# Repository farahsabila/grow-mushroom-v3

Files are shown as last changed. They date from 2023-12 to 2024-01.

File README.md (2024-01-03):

# IoT-based Mushroom Cultivation Device v3
This was my Exhibition Project that I showcased at INAGRITECH 2023 on August 23 - 25, 2023. This prototype was made for growing any mushroom at home. 

Pameran

## How It Works
Air humidity, air temperature, and light intensity are being monitored and controlled using IoT Technology. 

With these parameter specifications:
1. Air humidity: 70 % - 95 %
2. Air temperature: 20 °C - 25 °C
3. Light intensity: 300 lx - 500 lx

This range parameter specification can be adjusted according to the type of mushroom being chosen.

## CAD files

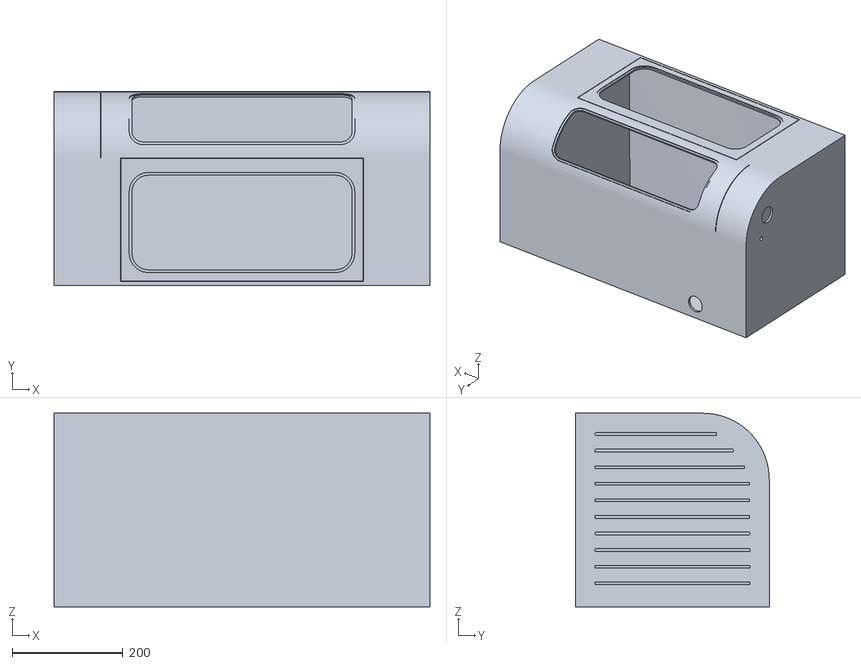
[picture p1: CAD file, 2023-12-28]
Casing/Main Casing.stl
680.0 x 350.0 x 350.0

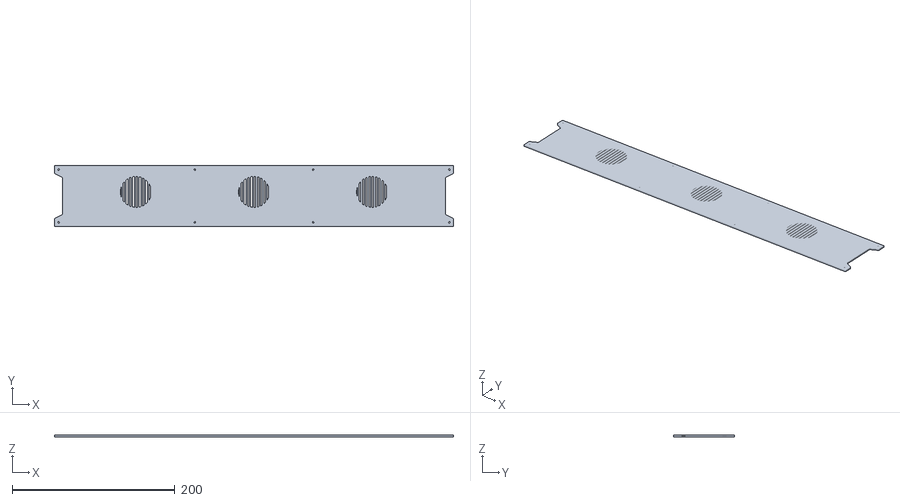
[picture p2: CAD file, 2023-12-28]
Casing/Inside Fan Closure/Lid_Closure.stl
490.0 x 75.0 x 2.00

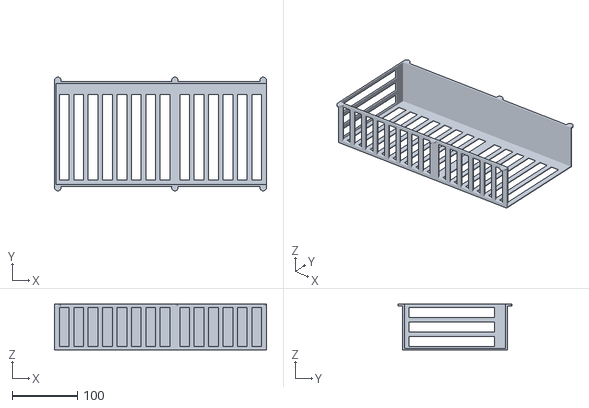
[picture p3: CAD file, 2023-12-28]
Casing/Outside Fan Closure/Right Body.stl
324.0 x 174.0 x 70.0

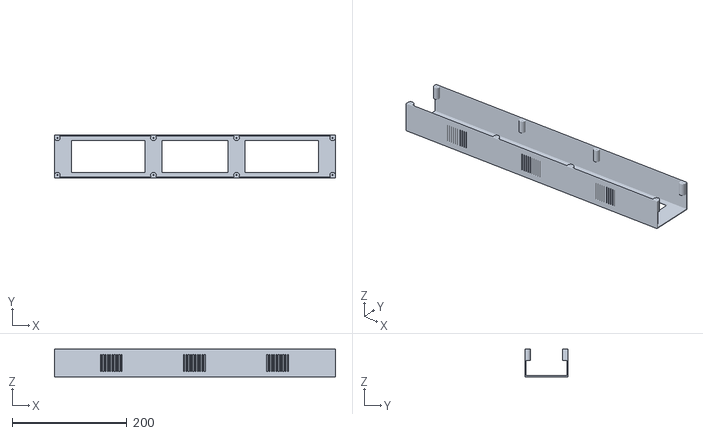
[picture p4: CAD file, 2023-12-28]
Casing/Inside Fan Closure/Body_Closure.stl
490.0 x 75.0 x 48.0

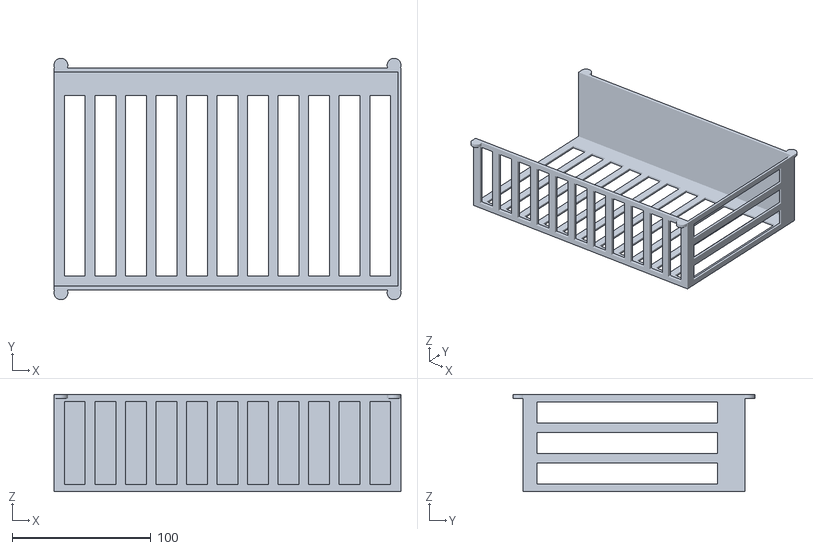
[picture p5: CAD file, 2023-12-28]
Casing/Outside Fan Closure/Left Body.stl
250.0 x 174.0 x 70.0

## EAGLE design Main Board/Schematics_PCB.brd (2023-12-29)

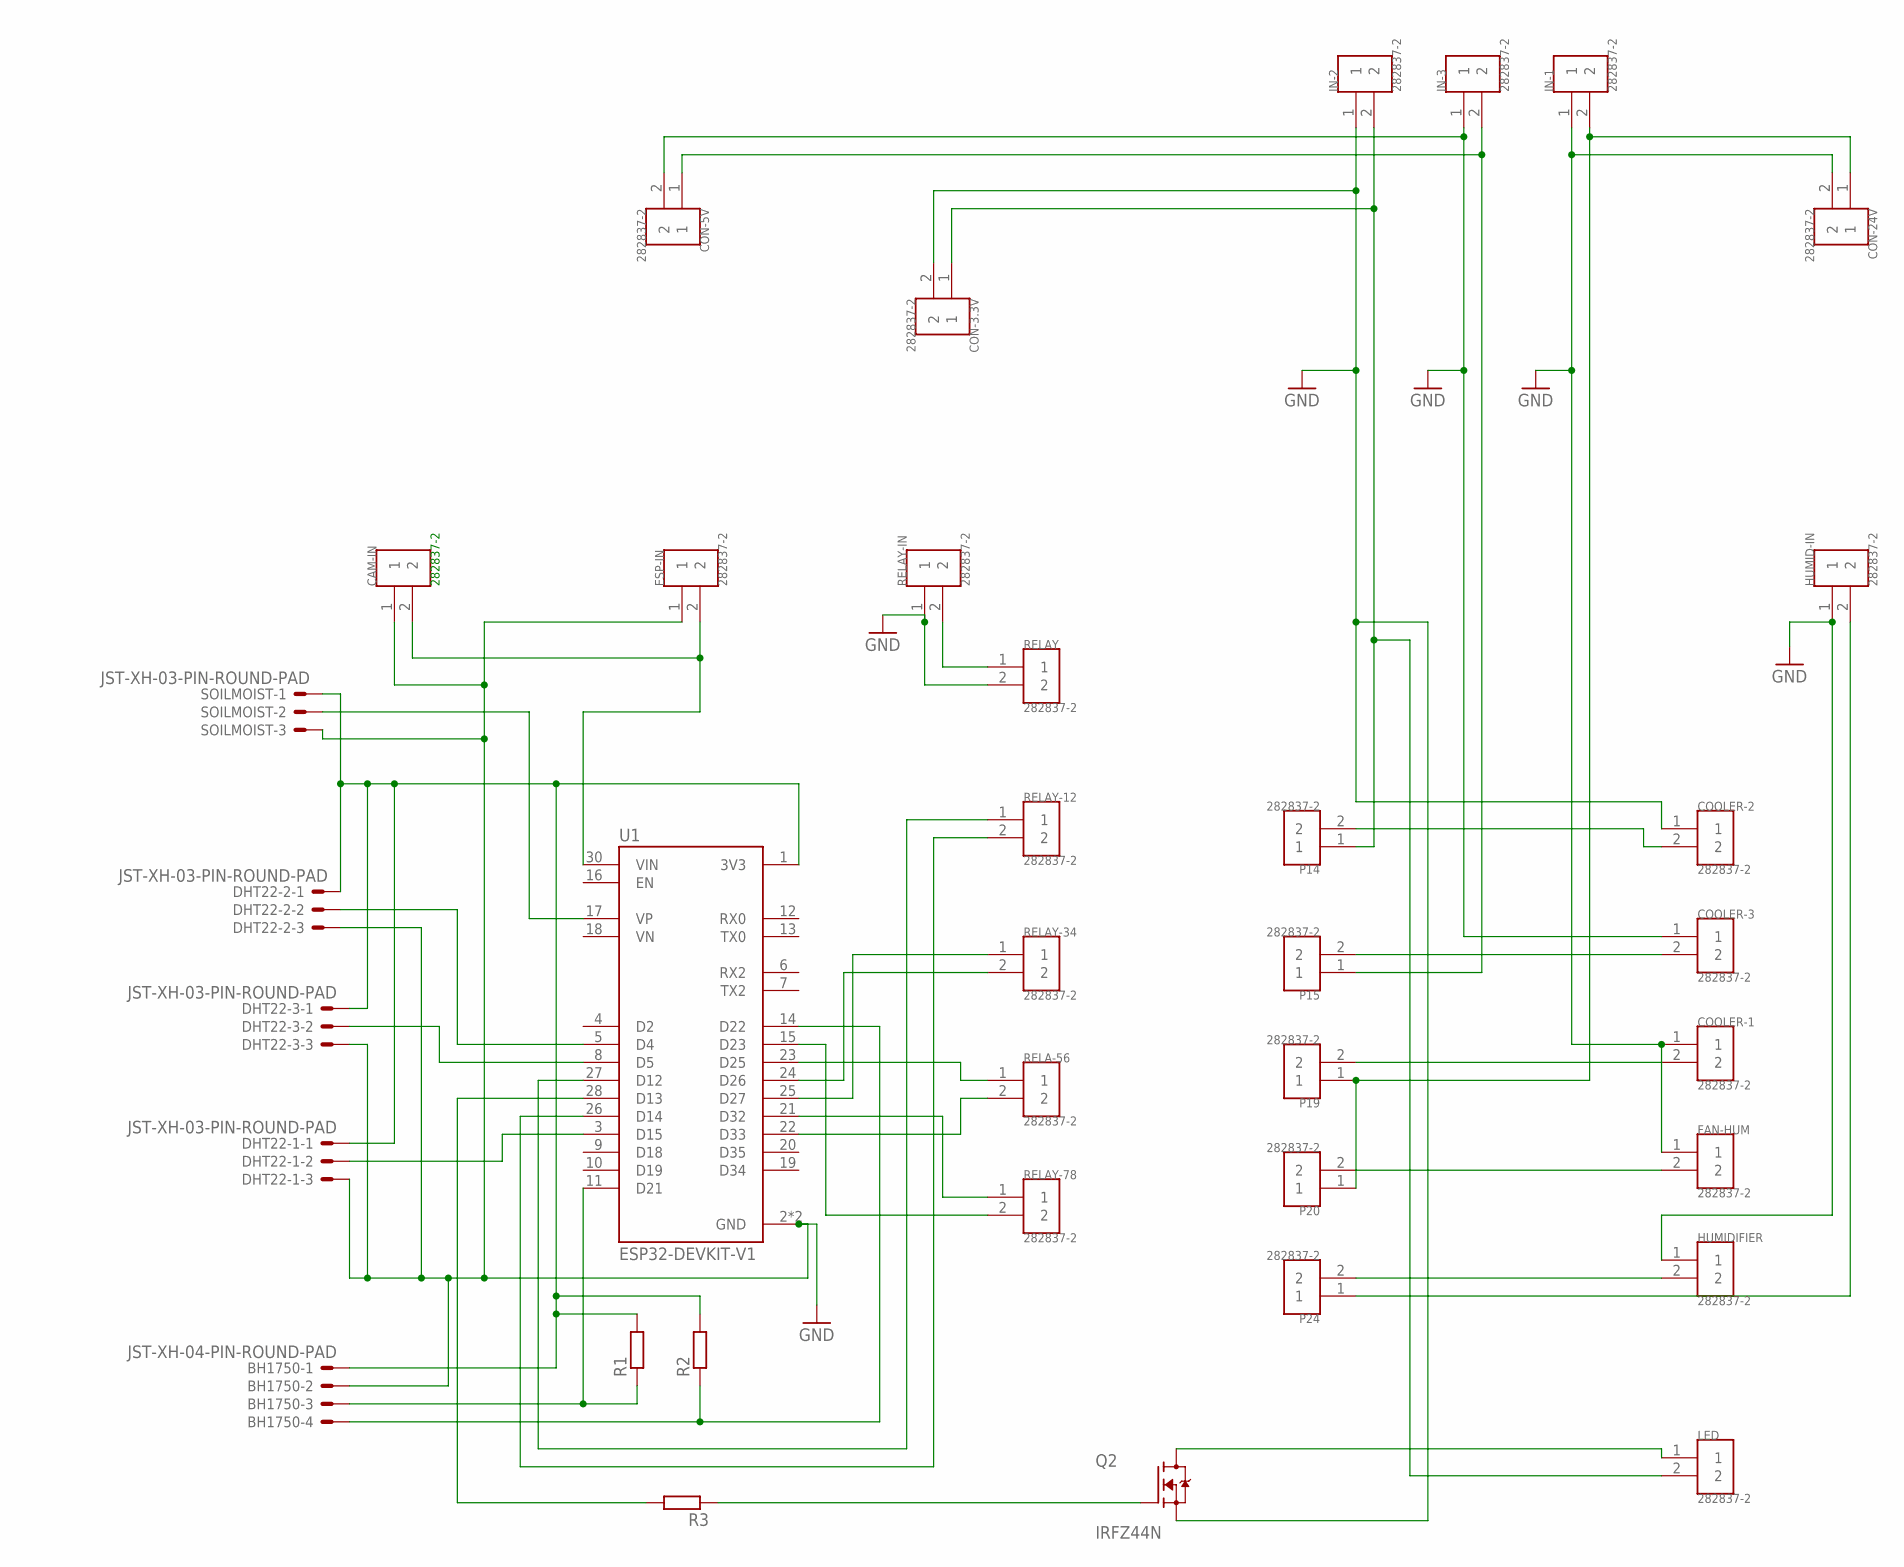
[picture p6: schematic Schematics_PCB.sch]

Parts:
BH1750: JST-XH-04-PIN-ROUND-PAD; JST-XH-04-PACKAGE-ROUND-PAD
CAM-IN: 282837-2; TE_282837-2
CON-3.3V, CON-5V, CON-24V: 282837-2; TE_282837-2
COOLER-1, COOLER-2, COOLER-3: 282837-2; TE_282837-2
DHT22-1, DHT22-2, DHT22-3: JST-XH-03-PIN-ROUND-PAD; JST-XH-03-PACKAGE-ROUND-PAD
ESP-IN: 282837-2; TE_282837-2
FAN-HUM: 282837-2; TE_282837-2
HUMID-IN: 282837-2; TE_282837-2
HUMIDIFIER: 282837-2; TE_282837-2
IN-1, IN-2, IN-3: 282837-2; TE_282837-2
LED: 282837-2; TE_282837-2
P14, P15, P19, P20, P24: 282837-2; TE_282837-2
Q2: IRFZ44N; TO254P1016X419X2286-3
R1, R2, R3: R-EU_0207/10; 0207/10
RELA-56: 282837-2; TE_282837-2
RELAY: 282837-2; TE_282837-2
RELAY-12, RELAY-34, RELAY-78: 282837-2; TE_282837-2
RELAY-IN: 282837-2; TE_282837-2
SOILMOIST: JST-XH-03-PIN-ROUND-PAD; JST-XH-03-PACKAGE-ROUND-PAD
U1: ESP32-DEVKIT-V1; MODULE_ESP32_DEVKIT_V1

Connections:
GND: BH1750.2, CAM-IN.1, CON-3.3V.2, CON-5V.2, CON-24V.2, COOLER-1.1, COOLER-2.1, COOLER-3.1, DHT22-1.3, DHT22-2.3, DHT22-3.3, ESP-IN.1, FAN-HUM.1, HUMID-IN.1, HUMIDIFIER.1, IN-1.1, IN-2.1, IN-3.1, Q2.3 (S), RELAY.2, RELAY-IN.1, SOILMOIST.3, U1.2 (GND), U1.29 (GND)
unnamed: DHT22-2.2, U1.5 (D4)
unnamed: DHT22-3.2, U1.8 (D5)
unnamed: SOILMOIST.2, U1.17 (VP)
unnamed: DHT22-1.2, U1.3 (D15)
unnamed: BH1750.1, DHT22-1.1, DHT22-2.1, DHT22-3.1, R1.2, R2.2, SOILMOIST.1, U1.1 (3V3)
unnamed: RELAY-12.1, U1.27 (D12)
unnamed: BH1750.3, R1.1, U1.11 (D21)
unnamed: BH1750.4, R2.1, U1.14 (D22)
unnamed: RELAY-12.2, U1.26 (D14)
unnamed: RELAY-34.1, U1.25 (D27)
unnamed: RELAY-34.2, U1.24 (D26)
unnamed: RELA-56.1, U1.23 (D25)
unnamed: RELA-56.2, U1.22 (D33)
unnamed: RELAY-78.1, U1.21 (D32)
unnamed: RELAY-78.2, U1.15 (D23)
unnamed: CAM-IN.2, ESP-IN.2, U1.30 (VIN)
unnamed: RELAY.1, RELAY-IN.2
unnamed: CON-3.3V.1, IN-2.2, LED.2, P14.1
unnamed: COOLER-2.2, P14.2
unnamed: CON-5V.1, IN-3.2, P15.1
unnamed: COOLER-3.2, P15.2
unnamed: CON-24V.1, IN-1.2, P19.1, P20.1
unnamed: COOLER-1.2, P19.2
unnamed: FAN-HUM.2, P20.2
unnamed: HUMIDIFIER.2, P24.2
unnamed: HUMID-IN.2, P24.1
unnamed: R3.2, U1.28 (D13)
unnamed: Q2.1 (G), R3.1
unnamed: LED.1, Q2.2 (D)

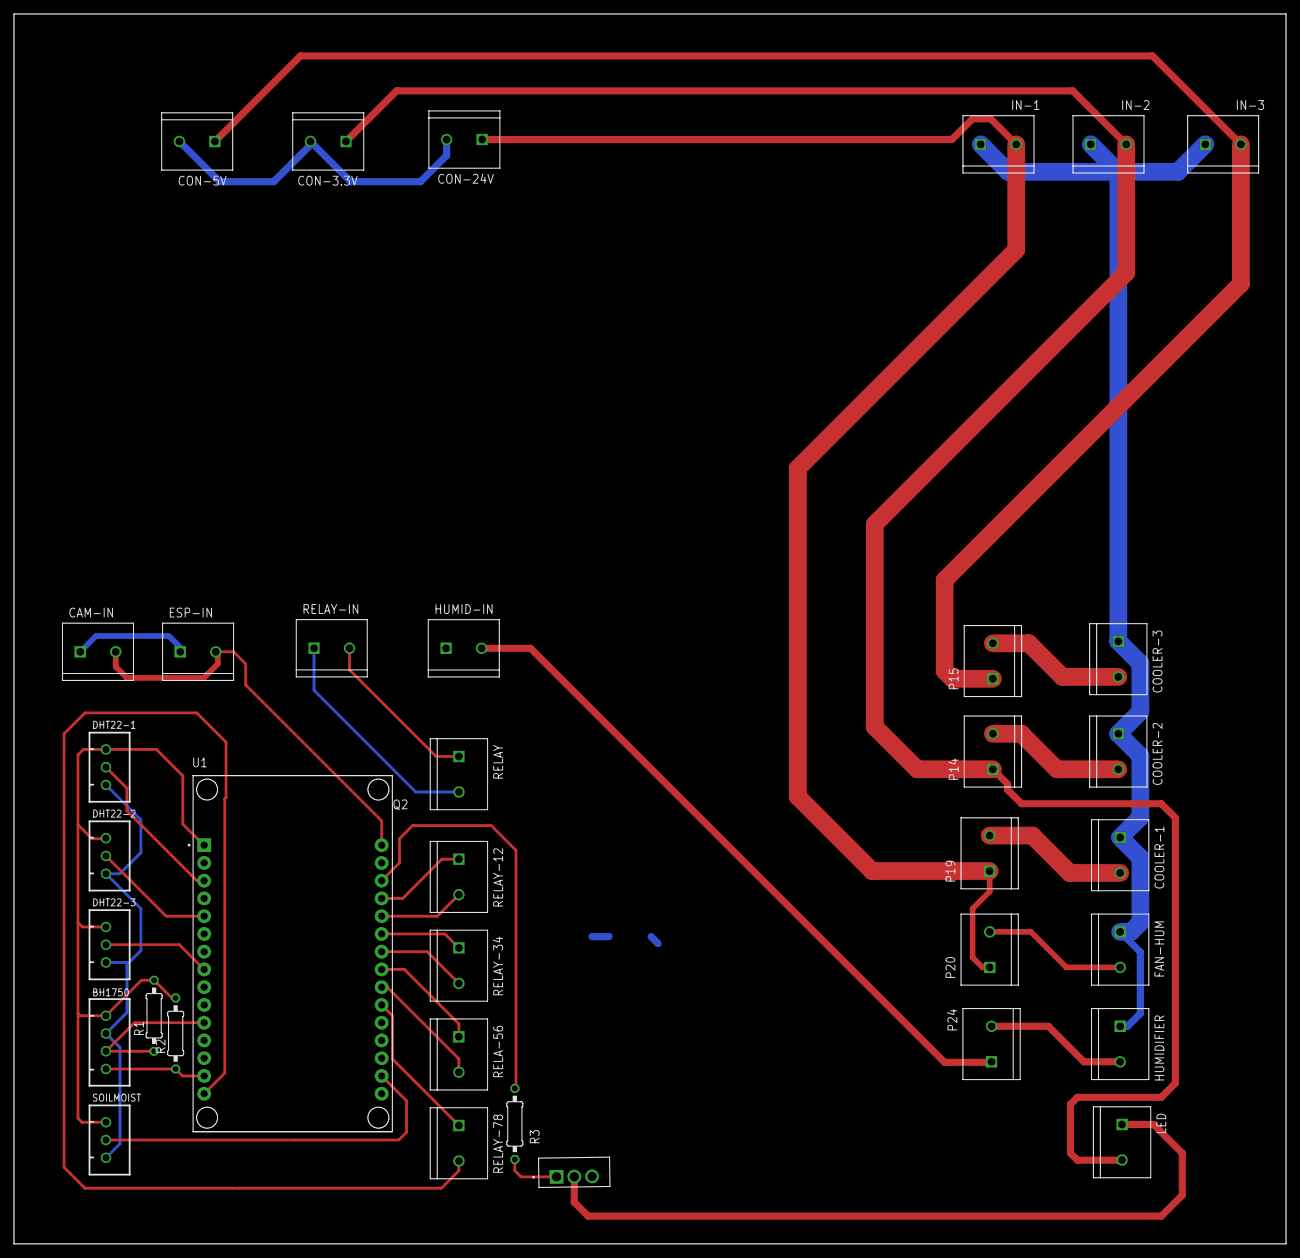
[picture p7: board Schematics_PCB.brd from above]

Board: 2 copper layers, 182.0 x 176.0 mm, 36 parts (0 on the bottom side), 30 nets.

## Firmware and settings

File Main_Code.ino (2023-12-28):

/*************************************************************

  This is a code for controlling mushroom chamber environment
 *************************************************************/

/* Information from Blynk Device Info */
#define BLYNK_TEMPLATE_ID "******************"
#define BLYNK_TEMPLATE_NAME "Mushroom Chamber"
#define BLYNK_AUTH_TOKEN "*******************"

/* Comment this out to disable prints and save space */
#define BLYNK_PRINT Serial

#include <WiFi.h>
#include <WiFiClient.h>
#include <BlynkSimpleEsp32.h>

// WiFi credentials
char ssid[] = "********";
char pass[] = "********";

BlynkTimer timer;

// Temperature and humidity sensors library, pins, and variables
#include <DHT.h>
DHT dht[] = {
  {15, DHT22},
  {4, DHT22},
  {5, DHT22},
};
double temp_set = 25;
double humidity_set = 90;

//Capacitive soil moisture variables
const int soilpin = A0;
const int AirValue = 2750;  
const int WaterValue = 1150;
int soilMoistureValue = 0;
int soilmoisturepercent = 0;

//Light intensity sensor library, pins, and variables
#include <BH1750.h>
#include <Wire.h>
BH1750 lightMeter;
uint16_t lux;

//Variables for Control LED Strip
int dutyCycle = 0;
/* Setting PWM Properties */
const int PWMFreq = 5000; /* 5 KHz */
const int PWMChannel = 0;
const int PWMResolution = 12;
const int MAX_DUTY_CYCLE = (int)(pow(2, PWMResolution) - 1);
const int ledStrip = 13;
int lux_set = 500;

//Declare actuators pins and variables
#define fan 25
#define ventilation_fan 12
#define humidifier 33
#define cooler1 14
#define cooler2 26
#define cooler3 27

//Variables for Timer/Millis.
unsigned long previousMillis = 0;
uint64_t interval = 5 * 60 * 1000; //--> Capture and Send a photo every 20 seconds.
int fan_setup = 1;

//Other variables needed
#define SDA 21
#define SCL 22

// This function is called every time the Virtual Pins state changes
BLYNK_WRITE(V0)
{
  // Set incoming value from pin V0 to a variable
  temp_set = param.asDouble();
  Serial.print("Temp Set: ");
  Serial.println(temp_set);
}

BLYNK_WRITE(V7)
{
  // Set incoming value from pin V7 to a variable
  humidity_set = param.asDouble();
  Serial.print("Humidity Set: ");
  Serial.println(humidity_set);
}

BLYNK_WRITE(V8)
{
  // Set incoming value from pin V8 to a variable
  lux_set = param.asInt();
  Serial.print("Light Set: ");
  Serial.println(lux_set);
}

void temp_control() {
  double temp[3];
  bool eventTrigger = false;
  for (int i = 0; i < 3; i++) {
    temp[i] = dht[i].readTemperature();
  }

  Serial.println("");
  Serial.print("Temp: ");
  for (int i = 0; i < 3; i++) {
    Serial.print(temp[i]);
    Serial.print("|");
  }
  Serial.println("");

  // Update actual temperature value to pin v1, v2, and v3 in Blynk
  Blynk.virtualWrite(V1, temp[0]);
  Blynk.virtualWrite(V2, temp[1]);
  Blynk.virtualWrite(V3, temp[2]);

  double range1 = 0.5;
  double range2 = 0.5;

  if (temp[0] > temp_set + range1) {
    digitalWrite(cooler1, HIGH);
    digitalWrite(cooler2, HIGH);
  }
  else if (temp[0] <= temp_set - range1) {
    digitalWrite(cooler1, LOW);
    digitalWrite(cooler2, LOW);
  }

  if (temp[1] > temp_set + range2) {
    digitalWrite(cooler3, HIGH);
  }
  else if (temp[0] <= temp_set - range2) {
    digitalWrite(cooler3, LOW);
  }

  if (temp[0] > (temp_set + range2) && eventTrigger == false) {
    eventTrigger = true;
    //Serial.println(eventTrigger);
    Blynk.logEvent("temperature_alert", String("Temperature is ") + temp[0] + String(" °C now, greater than ") + temp_set + String(" °C. Please check the cooling system!"));
  }
  else if(temp[0] <= (temp_set + range2)){
    eventTrigger = false;
  }
}

void humidity_control() {
  double humid[3];
  bool eventTrigger = false;
  
  for (int i = 0; i < 3; i++) {
    humid[i] = dht[i].readHumidity();
  }

  Serial.println("");
  Serial.print("Humidity: ");
  for (int i = 0; i < 3; i++) {
    Serial.print(humid[i]);
    Serial.print("|");
  }

  // Update actual temperature value to pin V2 in Blynk
  Blynk.virtualWrite(V4, humid[0]);
  Blynk.virtualWrite(V5, humid[1]);
  Blynk.virtualWrite(V6, humid[2]);
  
  if (humid[0] < humidity_set) {
    digitalWrite(humidifier, HIGH);
    digitalWrite(fan, HIGH);
  }
  else {
    digitalWrite(humidifier, LOW);
    digitalWrite(fan, LOW);
  }

  if (humid[1] < humidity_set) {
    digitalWrite(humidifier, HIGH);
    digitalWrite(fan, HIGH);
  }
  else {
    digitalWrite(humidifier, LOW);
    digitalWrite(fan, LOW);
  }
  int range = 5;
  if (humid[0] < (humidity_set - range) && eventTrigger == false) {
    eventTrigger = true;
    //Serial.println(eventTrigger); 
    Blynk.logEvent("humidity_alert", String("Humidity is ") + humid[0] + String("% now, lower than ") + humidity_set + String("%. Please check the humidifier and water reservoir level!"));
  }
  else if(humid[0] >= (humidity_set - range)){
    eventTrigger = false;
  }
}

void soil_moisture() {
  soilMoistureValue = analogRead(soilpin);
  Serial.println(soilMoistureValue);
  soilmoisturepercent = map(soilMoistureValue, AirValue, WaterValue, 0, 100);
  if(soilmoisturepercent > 100){
    Serial.println("100 %");
  }
  else if(soilmoisturepercent <0){
    Serial.println("0 %");
  }
  else if(soilmoisturepercent >=0 && soilmoisturepercent <= 100){
    Serial.print(soilmoisturepercent);
    Serial.println("%");
  }

  Blynk.virtualWrite(V10, soilmoisturepercent);
}

void light_control() {
  bool eventTrigger = false;
  if (lightMeter.begin()) {
    lux = lightMeter.readLightLevel();
    //Serial.println("");
    Serial.print("Light(lx): ");
    Serial.println(lux);
  }
  else {
    Serial.println(F("Error initialising BH1750"));
  }

  Blynk.virtualWrite(V9, lux);

  while(lux < lux_set && dutyCycle <= MAX_DUTY_CYCLE){
    /* Increasing the LED brightness with PWM */
    dutyCycle++;
    ledcWrite(PWMChannel, dutyCycle);
    delay(3);
    //delayMicroseconds(100);
  }
  while(lux > lux_set && dutyCycle >= 0){
    /* Decreasing the LED brightness with PWM */
    dutyCycle--;
    ledcWrite(PWMChannel, dutyCycle);
    delay(3);
    //delayMicroseconds(100);
  }

  int range = 100;
  if (lux > (lux_set + range) && eventTrigger == false) {
    eventTrigger = true;  
    //Serial.println(eventTrigger); 
    Blynk.logEvent("light_alert", String("Light intensity is ") + lux + String(" lux now, greater than ") + lux_set + String("%. Please check the light system!"));
  }
  else if(lux <= (lux_set + range)){
    eventTrigger = false;
  }
}

void setup()
{
  // Debug console
  Serial.begin(115200);
  for (int i = 0; i < 3; i++) {
    dht[i].begin();
  }

  pinMode(cooler1, OUTPUT);
  pinMode(cooler2, OUTPUT);
  pinMode(cooler3, OUTPUT);
  pinMode(fan, OUTPUT);
  pinMode(humidifier, OUTPUT);
  pinMode(ventilation_fan, OUTPUT);

  ledcSetup(PWMChannel, PWMFreq, PWMResolution);
  ledcAttachPin(ledStrip, PWMChannel);

  digitalWrite(ventilation_fan, HIGH);
  Serial.print("Ventilation fan ON");

  Wire.begin(SDA, SCL);
  pinMode(SDA, INPUT_PULLUP);
  pinMode(SCL, INPUT_PULLUP);
  lightMeter.begin();
  light_control();

  Blynk.begin(BLYNK_AUTH_TOKEN, ssid, pass);
  // You can also specify server:
  //Blynk.begin(BLYNK_AUTH_TOKEN, ssid, pass, "blynk.cloud", 80);
  //Blynk.begin(BLYNK_AUTH_TOKEN, ssid, pass, IPAddress(192,168,1,100), 8080);

  // Setup a function to be called every second
  //timer.setInterval(1500L, myTimerEvent);
  timer.setInterval(5000L, humidity_control);
  timer.setInterval(1000L, temp_control);
  timer.setInterval(5000L, light_control);
  timer.setInterval(1000L, soil_moisture);
}

void loop()
{
  Blynk.run();
  timer.run();

  if (fan_setup == 1) {
    interval = 5 * 60 * 1000;
  }
  else if (fan_setup == 0) {
    interval = 55 * 60 * 1000;
  }

  unsigned long currentMillis = millis();
  if (currentMillis - previousMillis >= interval) { 
    previousMillis = currentMillis;
    if (fan_setup == 1) {
      fan_setup = 0;
      digitalWrite(ventilation_fan, LOW);
      //Serial.println(fan_setup);
      Serial.println("Ventilation Fan OFF");
    }
    else if (fan_setup == 0) {
      fan_setup = 1;
      digitalWrite(ventilation_fan, HIGH);
      //Serial.println(fan_setup);
      Serial.println("Ventilation Fan ON");
    }
  }
}

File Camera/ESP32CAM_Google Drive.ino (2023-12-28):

//Including the libraries.
#include <WiFi.h>
#include <WiFiClientSecure.h>
#include "soc/soc.h"
#include "soc/rtc_cntl_reg.h"
#include "Base64.h"
#include "esp_camera.h"
#include "time.h"

//Timer 
const char* ntpServer = "pool.ntp.org";
const long  gmtOffset_sec = 3600*6;
const int   daylightOffset_sec = 3600;
int h, m, s;
int setHour[2] = {6, 18};
int setMinute = 0;
int setSecond = 0;

//CAMERA_MODEL_AI_THINKER GPIO.
#define PWDN_GPIO_NUM     32
#define RESET_GPIO_NUM    -1
#define XCLK_GPIO_NUM      0
#define SIOD_GPIO_NUM     26
#define SIOC_GPIO_NUM     27

#define Y9_GPIO_NUM       35
#define Y8_GPIO_NUM       34
#define Y7_GPIO_NUM       39
#define Y6_GPIO_NUM       36
#define Y5_GPIO_NUM       21
#define Y4_GPIO_NUM       19
#define Y3_GPIO_NUM       18
#define Y2_GPIO_NUM        5
#define VSYNC_GPIO_NUM    25
#define HREF_GPIO_NUM     23
#define PCLK_GPIO_NUM     22

//nter your WiFi ssid and password.
const char* ssid = "**************";
const char* password = "**********";

//Replace with your "Deployment ID" and Folder Name.
String myDeploymentID = "**************************";
String myMainFolderName = "Mushroom-Chamber";

#define uS_TO_S_FACTOR 1000000ULL  /* Conversion factor for micro seconds to seconds */
uint64_t TIME_TO_SLEEP = 30;        /* Time ESP32 will go to sleep (in seconds) */

RTC_DATA_ATTR int bootCount = 0;

// LED Flash PIN (GPIO 4)
#define FLASH_LED_PIN 4
bool LED_Flash_ON = true;

// Initialize WiFiClientSecure.
WiFiClientSecure client;


//Method to print the reason by which ESP32 has been awaken from sleep
void print_wakeup_reason(){
  esp_sleep_wakeup_cause_t wakeup_reason;

  wakeup_reason = esp_sleep_get_wakeup_cause();

  switch(wakeup_reason)
  {
    case ESP_SLEEP_WAKEUP_EXT0 : Serial.println("Wakeup caused by external signal using RTC_IO"); break;
    case ESP_SLEEP_WAKEUP_EXT1 : Serial.println("Wakeup caused by external signal using RTC_CNTL"); break;
    case ESP_SLEEP_WAKEUP_TIMER : Serial.println("Wakeup caused by timer"); break;
    case ESP_SLEEP_WAKEUP_TOUCHPAD : Serial.println("Wakeup caused by touchpad"); break;
    case ESP_SLEEP_WAKEUP_ULP : Serial.println("Wakeup caused by ULP program"); break;
    default : Serial.printf("Wakeup was not caused by deep sleep: %d\n",wakeup_reason); break;
  }
}

void printLocalTime(){
  char timeHour[3];
  char timeMinute[3];
  char timeSecond[3];
  
  struct tm timeinfo;
  if(!getLocalTime(&timeinfo)){
    Serial.println("Failed to obtain time");
    Serial.println("Restarting the ESP32 CAM.");
    delay(1000);
    ESP.restart();
    return;
  }
  Serial.println(&timeinfo, "%A, %B %d %Y %H:%M:%S");
  
  strftime(timeHour,3, "%H", &timeinfo);
  strftime(timeMinute,3, "%M", &timeinfo);
  strftime(timeSecond,3, "%S", &timeinfo);

  sscanf(timeHour, "%d", &h);
  sscanf(timeMinute, "%d", &m);
  sscanf(timeSecond, "%d", &s);
}

// This subroutine is to test the connection to "script.google.com".
void Test_Con() {
  const char* host = "script.google.com";
  while(1) {
    Serial.println("-----------");
    Serial.println("Connection Test...");
    Serial.println("Connect to " + String(host));
  
    client.setInsecure();
  
    if (client.connect(host, 443)) {
      Serial.println("Connection successful.");
      Serial.println("-----------");
      client.stop();
      break;
    } else {
      Serial.println("Connected to " + String(host) + " failed.");
      Serial.println("Wait a moment for reconnecting.");
      Serial.println("-----------");
      client.stop();
    }
  
    delay(1000);
  }
}

void capture_photo(){
  //The Flash LED blinks once to indicate connection start.
  digitalWrite(FLASH_LED_PIN, HIGH);
  delay(100);
  digitalWrite(FLASH_LED_PIN, LOW);
  delay(100);

  //The process of connecting, capturing and sending photos to Google Drive.   
  if (LED_Flash_ON == true) {
    digitalWrite(FLASH_LED_PIN, HIGH);
    delay(100);
  }

  //Taking a photo.
  Serial.println();
  Serial.println("Taking a photo...");
    
  for (int i = 0; i <= 3; i++) {
    camera_fb_t * fb = NULL;
    fb = esp_camera_fb_get();
     if(!fb) {
        Serial.println("Camera capture failed");
        Serial.println("Restarting the ESP32 CAM.");
        delay(1000);
        ESP.restart();
        return;
      } 
    esp_camera_fb_return(fb);
    delay(200);
  }

  camera_fb_t * fb = NULL;
  fb = esp_camera_fb_get();
  if(!fb) {
    Serial.println("Camera capture failed");
    Serial.println("Restarting the ESP32 CAM.");
    delay(1000);
    ESP.restart();
    return;
  } 

  if (LED_Flash_ON == true) digitalWrite(FLASH_LED_PIN, LOW);
  
  Serial.println("Taking a photo was successful.");
}

// Subroutine for capturing and sending photos to Google Drive.
void SendCapturedPhotos() {
  const char* host = "script.google.com";
  Serial.println();
  Serial.println("-----------");
  Serial.println("Connect to " + String(host));
  
  client.setInsecure();

  //The Flash LED blinks once to indicate connection start.
  digitalWrite(FLASH_LED_PIN, HIGH);
  delay(100);
  digitalWrite(FLASH_LED_PIN, LOW);
  delay(100);

  //The process of connecting, capturing and sending photos to Google Drive.
  if (client.connect(host, 443)) {
    Serial.println("Connection successful.");
    
    if (LED_Flash_ON == true) {
      digitalWrite(FLASH_LED_PIN, HIGH);
      delay(100);
    }

    //Taking a photo.
    Serial.println();
    Serial.println("Taking a photo...");
    
    for (int i = 0; i <= 3; i++) {
      camera_fb_t * fb = NULL;
      fb = esp_camera_fb_get();
       if(!fb) {
          Serial.println("Camera capture failed");
          Serial.println("Restarting the ESP32 CAM.");
          delay(1000);
          ESP.restart();
          return;
        } 
      esp_camera_fb_return(fb);
      delay(200);
    }
  
    camera_fb_t * fb = NULL;
    fb = esp_camera_fb_get();
    if(!fb) {
      Serial.println("Camera capture failed");
      Serial.println("Restarting the ESP32 CAM.");
      delay(1000);
      ESP.restart();
      return;
    } 
  
    if (LED_Flash_ON == true) digitalWrite(FLASH_LED_PIN, LOW);
    
    Serial.println("Taking a photo was successful.");
    

    //Sending image to Google Drive.
    Serial.println();
    Serial.println("Sending image to Google Drive.");
    Serial.println("Size: " + String(fb->len) + "byte");
    
    String url = "/macros/s/" + myDeploymentID + "/exec?folder=" + myMainFolderName;

    client.println("POST " + url + " HTTP/1.1");
    client.println("Host: " + String(host));
    client.println("Transfer-Encoding: chunked");
    client.println();

    int fbLen = fb->len;
    char *input = (char *)fb->buf;
    int chunkSize = 3 * 1000; //--> must be multiple of 3.
    int chunkBase64Size = base64_enc_len(chunkSize);
    char output[chunkBase64Size + 1];
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

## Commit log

2023-12-28 add: casing
    [Body_Closure.stl, Left Body.stl, Lid_Closure.stl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]
2023-12-28 add: camera code
2023-12-29 add: PCB design
    [Schematics_PCB.brd, Schematics_PCB.sch]
